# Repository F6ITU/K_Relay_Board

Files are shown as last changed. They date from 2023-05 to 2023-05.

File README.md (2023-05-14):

# K_Relay_Board
LA2NI's OpenHPSDR 4 ways HF relay board (Kicad Version)

OpenHPSDR P.A. Antenna switch board by LA2NI (Munin 400/Aries system)

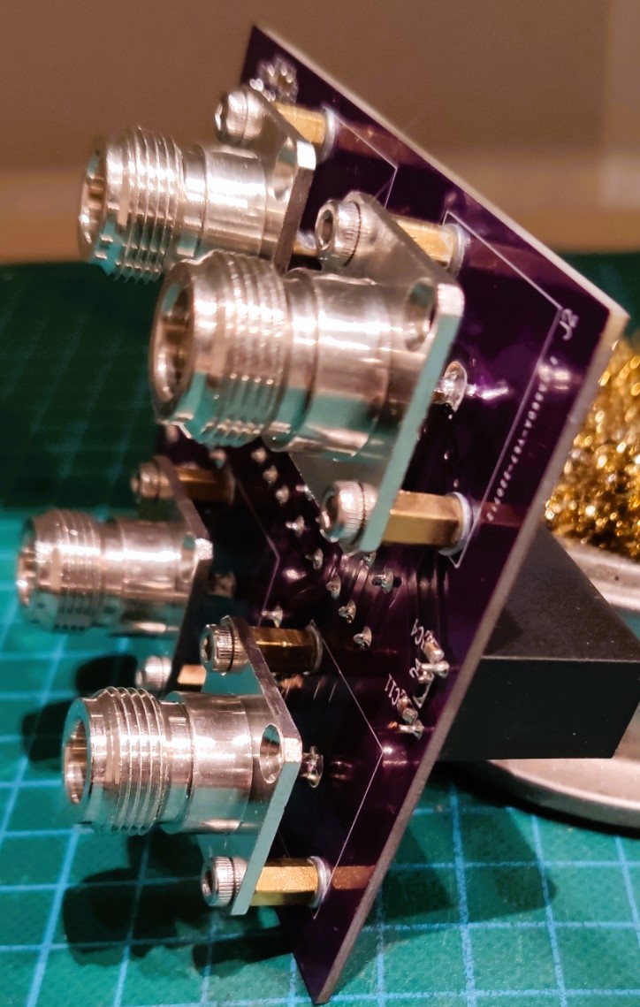
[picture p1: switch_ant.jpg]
La carte antenne


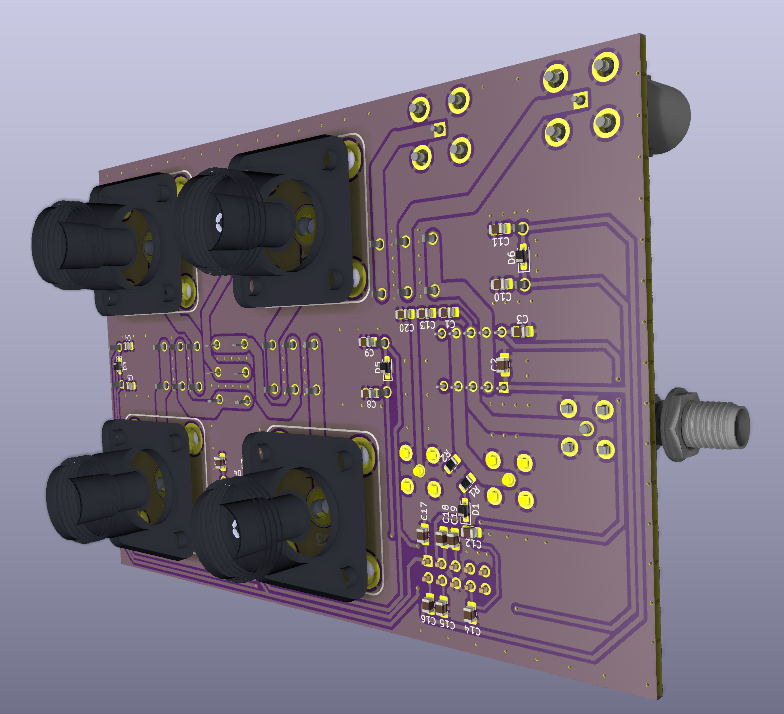
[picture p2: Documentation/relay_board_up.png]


This relay board is part of a set consisting of a 400 W LDMos based RF power amplifier (Munin 400), 
a medium power (600 or 1500 W) Zolotarev low pass filter, an Automatic Antenna Tuner (ATU) nickname « Aries » 
and a 4 port antenna switch (this project).

All these developments are the work and intellectual property of Kjell Karlsen LA2NI and Laurence Barker G8NJJ.

This original work can be downloaded from 

https://github.com/LA2NI/

https://github.com/laurencebarker

The Antenna switch board ensures the switching between 4 antennas under the control of the Aries ATU board. Each of the connected antennas
have a profile stored in the memory of the Aries MCU module. This way, switching from an antenna to the other don't need a new 
tuning solution if the couple "frequency/antenna" has already been defined. 

For more information, please refer to the Aries documentation (in the G8NJJ github repository)

This board was originally developed in September 2021 by Kjell LA2NI , with UltiBoard EDA. This repository is a « bug for bug » clone of the original Protection Board using the Opensource 
Kicad EDA. All these KiCad files are, consequently, the intellectual property of Kjell LA2NI.

This portage (convertion/translation) is placed under the CERN Open source/ Open hardware Licence.

Kicad is an Opensource EDA software maintained by the European Reseach Center CERN (Conseil européen pour la recherche nucléaire)

The original work is protected by the TAPR Open Hardware licence

# Work is RTM
Design is considered as finished, no prototype have been assembled so far. This project is RTM without waranty 

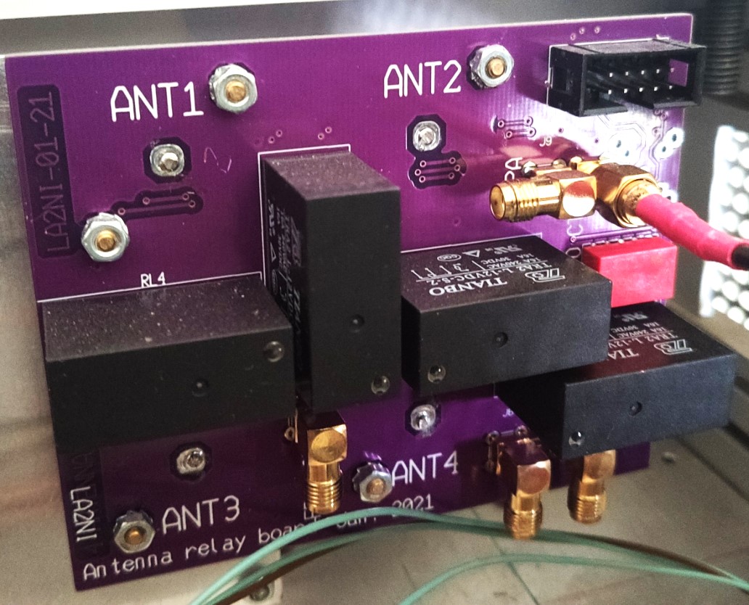
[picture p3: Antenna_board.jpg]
La carte antenne, verso

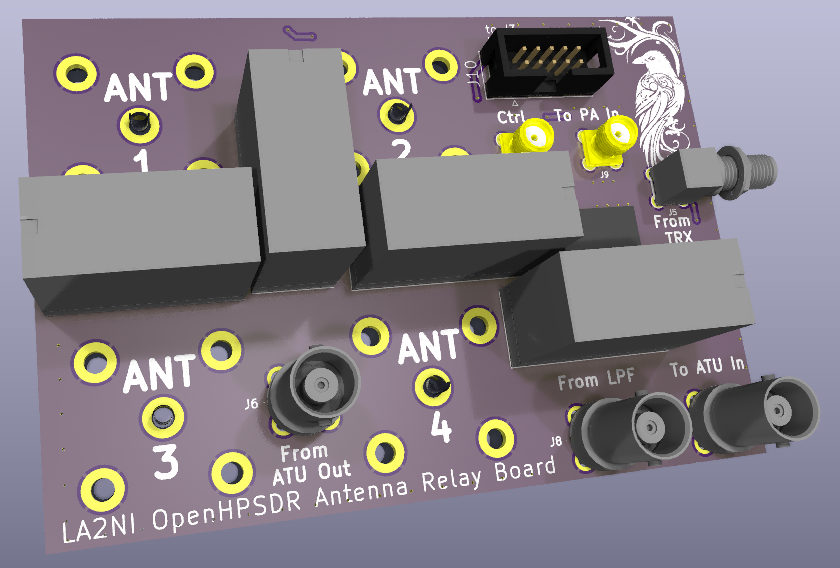
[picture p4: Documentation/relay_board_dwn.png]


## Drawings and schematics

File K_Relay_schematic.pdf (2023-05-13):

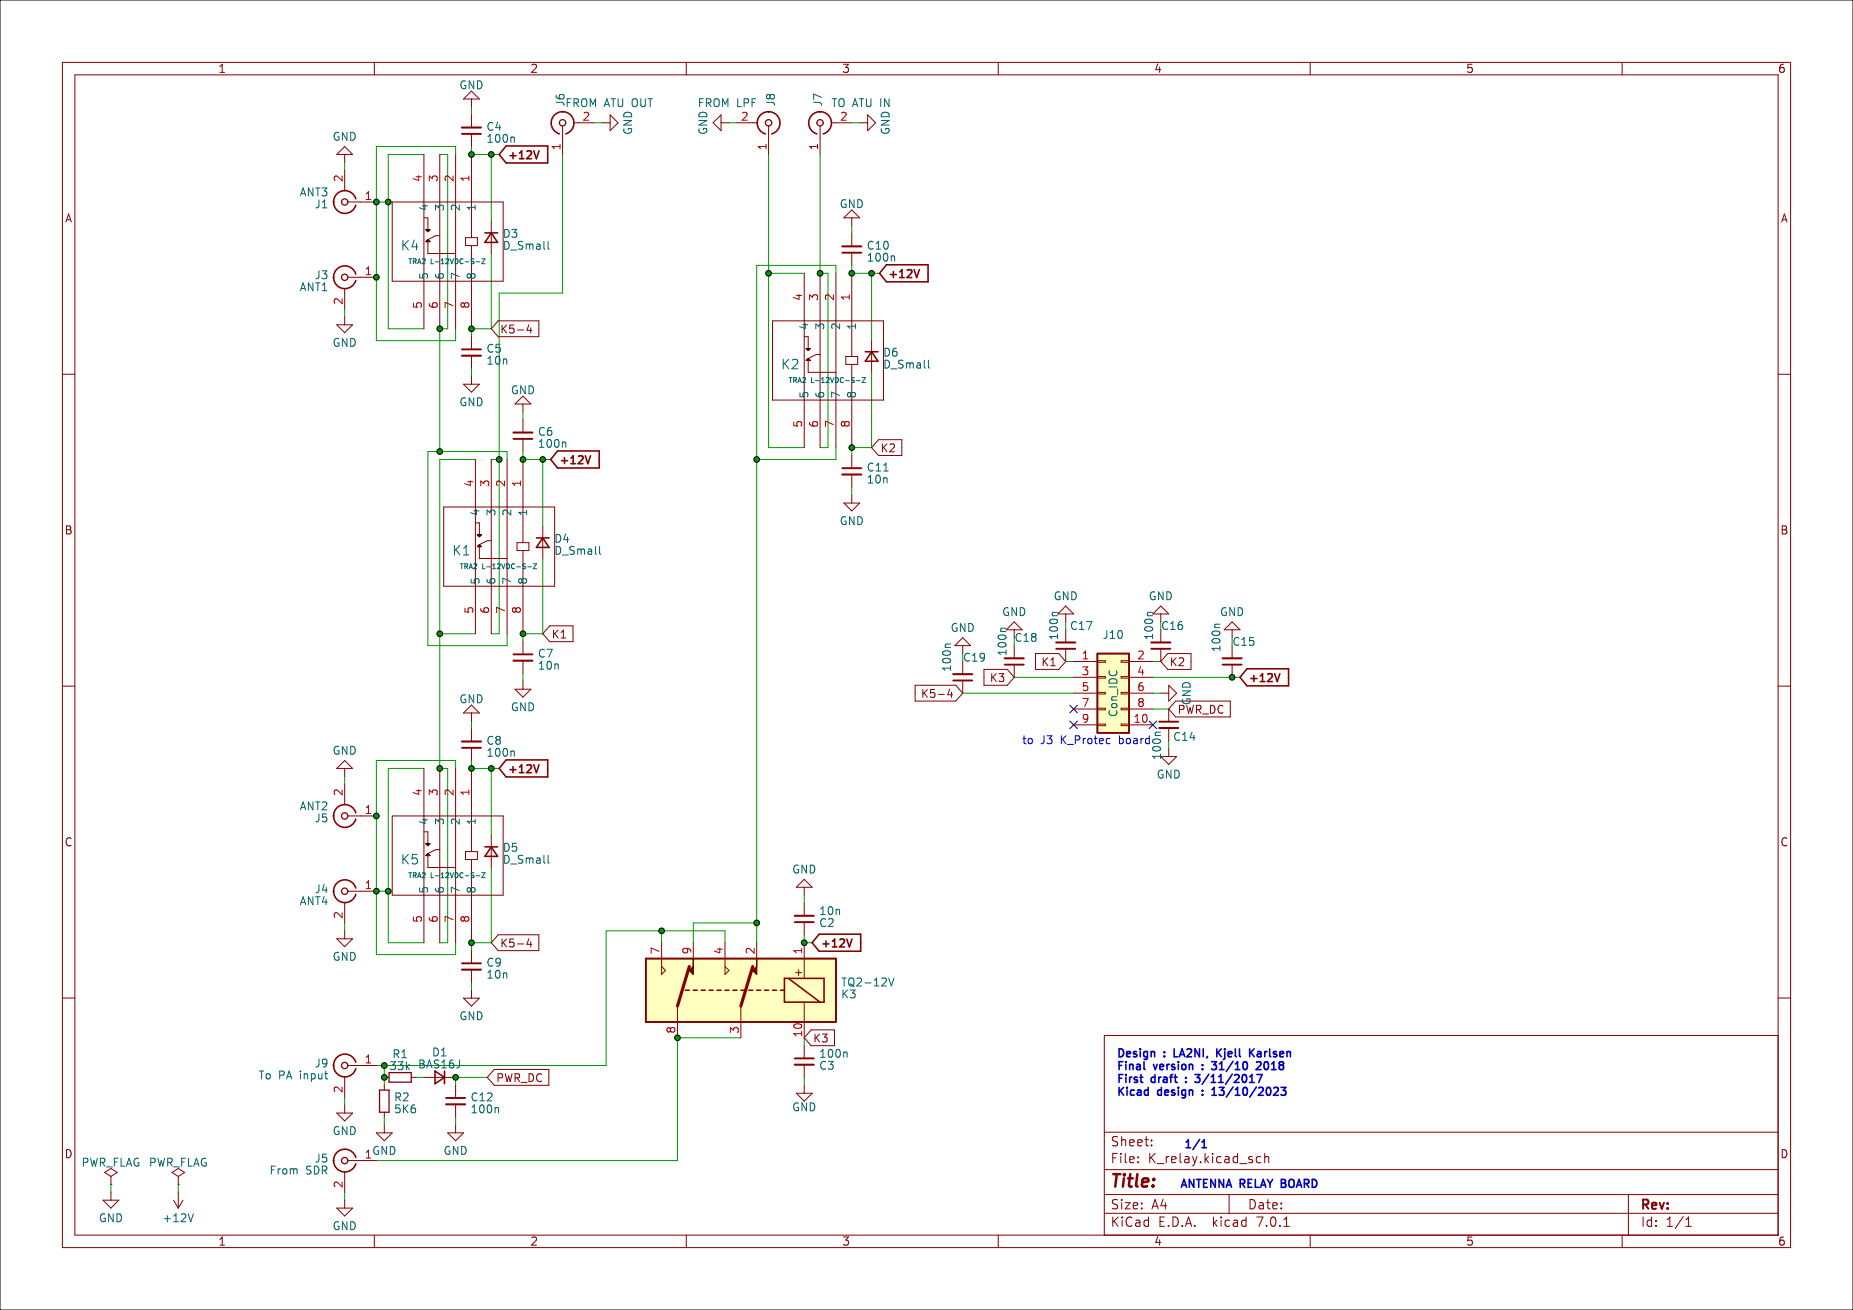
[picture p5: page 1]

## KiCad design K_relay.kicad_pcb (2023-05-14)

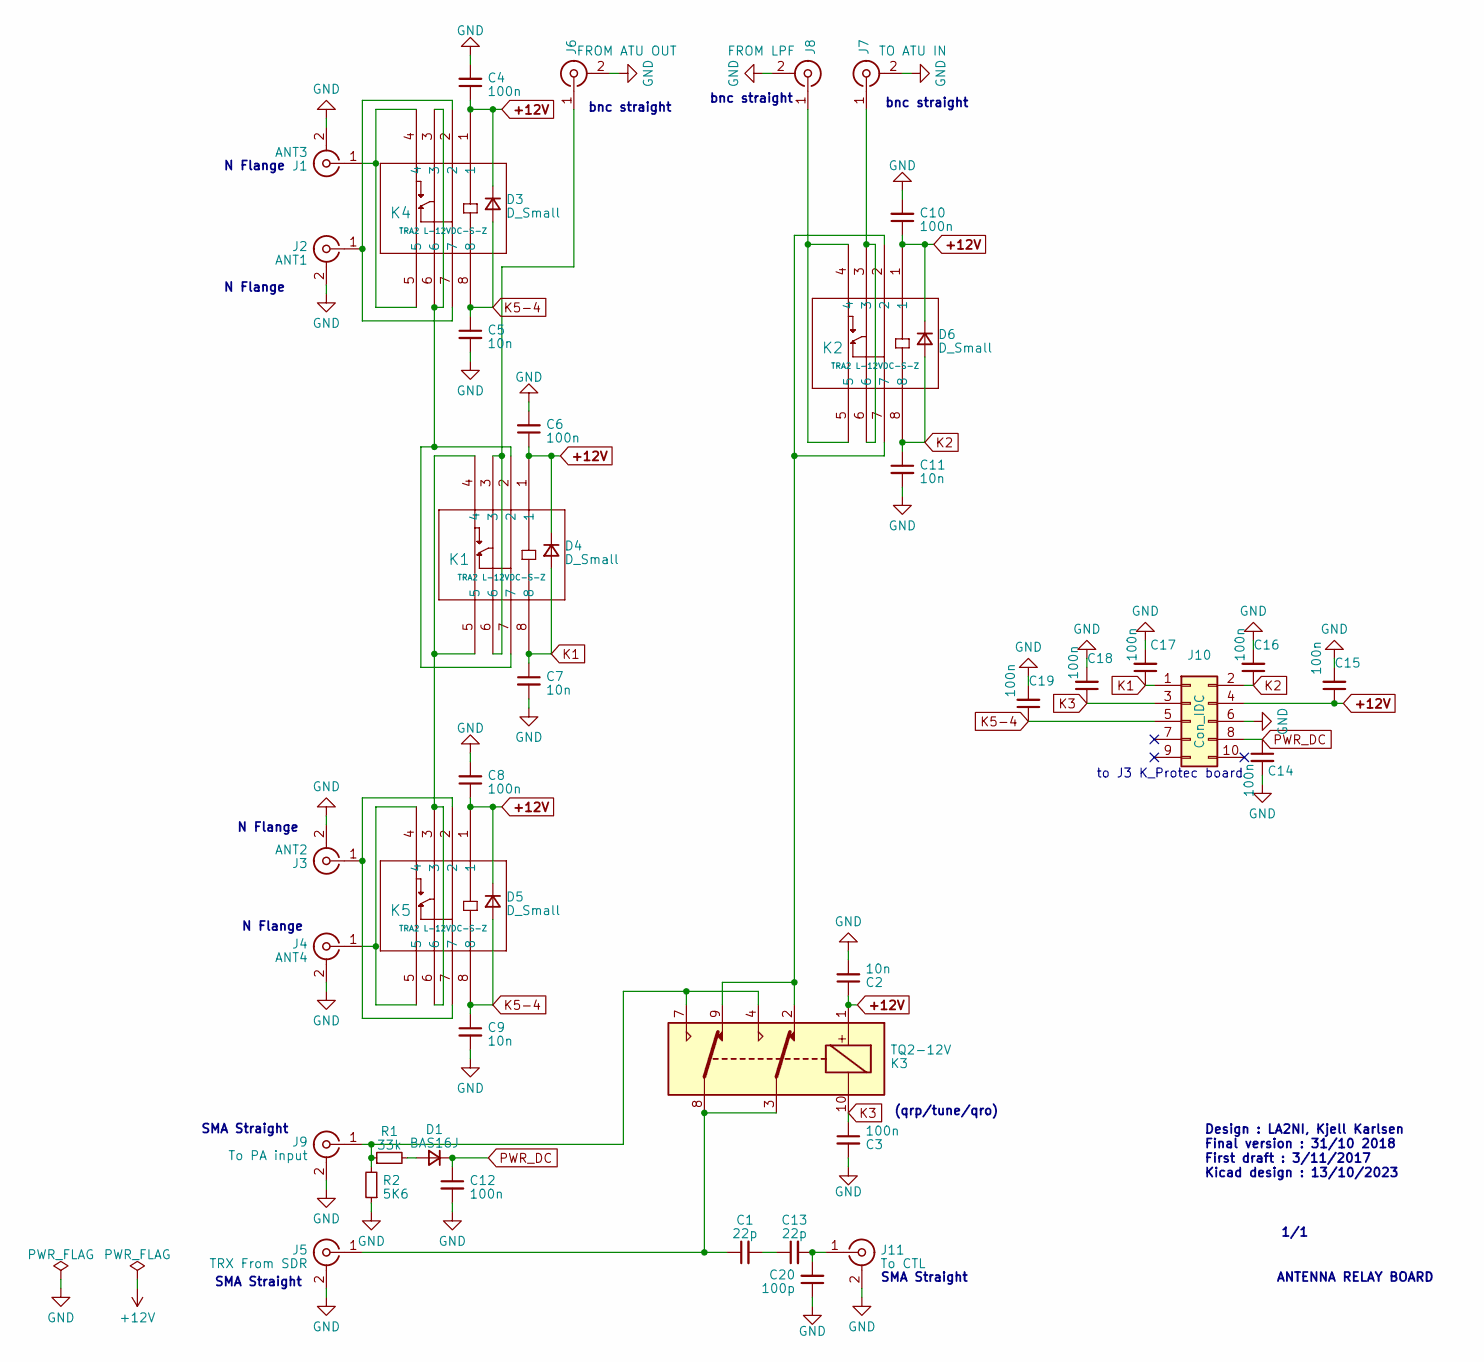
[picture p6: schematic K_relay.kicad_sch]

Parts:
C1, C13: 22p; C_0805_2012Metric_Pad1.18x1.45mm_HandSolder
C2, C5, C7, C9, C11: 10n; C_0805_2012Metric_Pad1.18x1.45mm_HandSolder
C3, C4, C6, C8, C10, C12, C14, C15, C16, C17, C18, C19: 100n; C_0805_2012Metric_Pad1.18x1.45mm_HandSolder
C20: 100p; C_0805_2012Metric_Pad1.18x1.45mm_HandSolder
D1: BAS16J; D_SOD-323_HandSoldering
D3, D4, D5, D6: D_Small; D_SOD-323_HandSoldering
J1: ANT3; Coaxial_N_Flange
J2: ANT1; Coaxial_N_Flange
J3: ANT2; Coaxial_N_Flange
J4: ANT4; Coaxial_N_Flange
J5: TRX From SDR; SMA_PINS
J6: FROM ATU OUT; BNC_Amphenol_031532951RFX
J7: TO ATU IN; BNC_Amphenol_031532951RFX
J8: FROM LPF; BNC_Amphenol_031532951RFX
J9: To PA input; SMA_PINS
J10: Con_IDC; IDC-Header_2x05_P2.54mm_Vertical
J11: To CTL; SMA_PINS
K1, K2, K4, K5: TRA2 L-12VDC-S-Z; RELAY_G2R-1-E AC12
K3: TQ2-12V; DIPS762W80P254L1400H530Q10N
R1: 33k; R_0805_2012Metric_Pad1.20x1.40mm_HandSolder
R2: 5K6; R_0805_2012Metric_Pad1.20x1.40mm_HandSolder

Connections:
+12V: C2.1, C4.1, C6.1, C8.1, C10.1, C15.1, D3.1 (K), D4.1 (K), D5.1 (K), D6.1 (K), J10.4, K1.1, K2.1, K3.1, K4.1, K5.1
GND: C2.2, C3.2, C4.2, C5.2, C6.2, C7.2, C8.2, C9.2, C10.2, C11.2, C12.2, C14.2, C15.2, C16.2, C17.2, C18.2, C19.2, C20.1, J1.2 (Ext), J2.2 (Ext), J3.2 (Ext), J4.2 (Ext), J5.2 (Ext), J6.2 (Ext), J7.2 (Ext), J8.2 (Ext), J9.2 (Ext), J10.6, J11.2 (Ext), R2.1
K1: C7.1, C17.1, D4.2 (A), J10.1, K1.8
K2: C11.1, C16.1, D6.2 (A), J10.2, K2.8
K3: C3.1, C18.1, J10.3, K3.10
K5-4: C5.1, C9.1, C19.1, D3.2 (A), D5.2 (A), J10.5, K4.8, K5.8
unnamed: C1.2, C13.1
unnamed: D1.2 (A), R1.2
unnamed: J1.1 (In), K4.4, K4.5
unnamed: J2.1 (In), K4.2, K4.7
unnamed: J3.1 (In), K5.2, K5.7
unnamed: J4.1 (In), K5.4, K5.5
unnamed: C1.1, J5.1 (In), K3.3, K3.8
unnamed: J6.1 (In), K1.3, K1.6
unnamed: J7.1 (In), K2.3, K2.6
unnamed: J8.1 (In), K2.4, K2.5
unnamed: J9.1 (In), K3.4, K3.7, R1.1, R2.2
unnamed: C13.2, C20.2, J11.1 (In)
unnamed: K1.2, K1.7, K4.3, K4.6
unnamed: K1.4, K1.5, K5.3, K5.6
unnamed: K2.2, K2.7, K3.2, K3.9
PWR_DC: C12.1, C14.1, D1.1 (K), J10.8

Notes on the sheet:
to J3 K_Protec board
N Flange
bnc straight
SMA Straight
1/1
Design : LA2NI, Kjell Karlsen Final version : 31/10 2018 First draft : 3/11/2017 Kicad design : 13/10/2023
(qrp/tune/qro)
ANTENNA RELAY BOARD

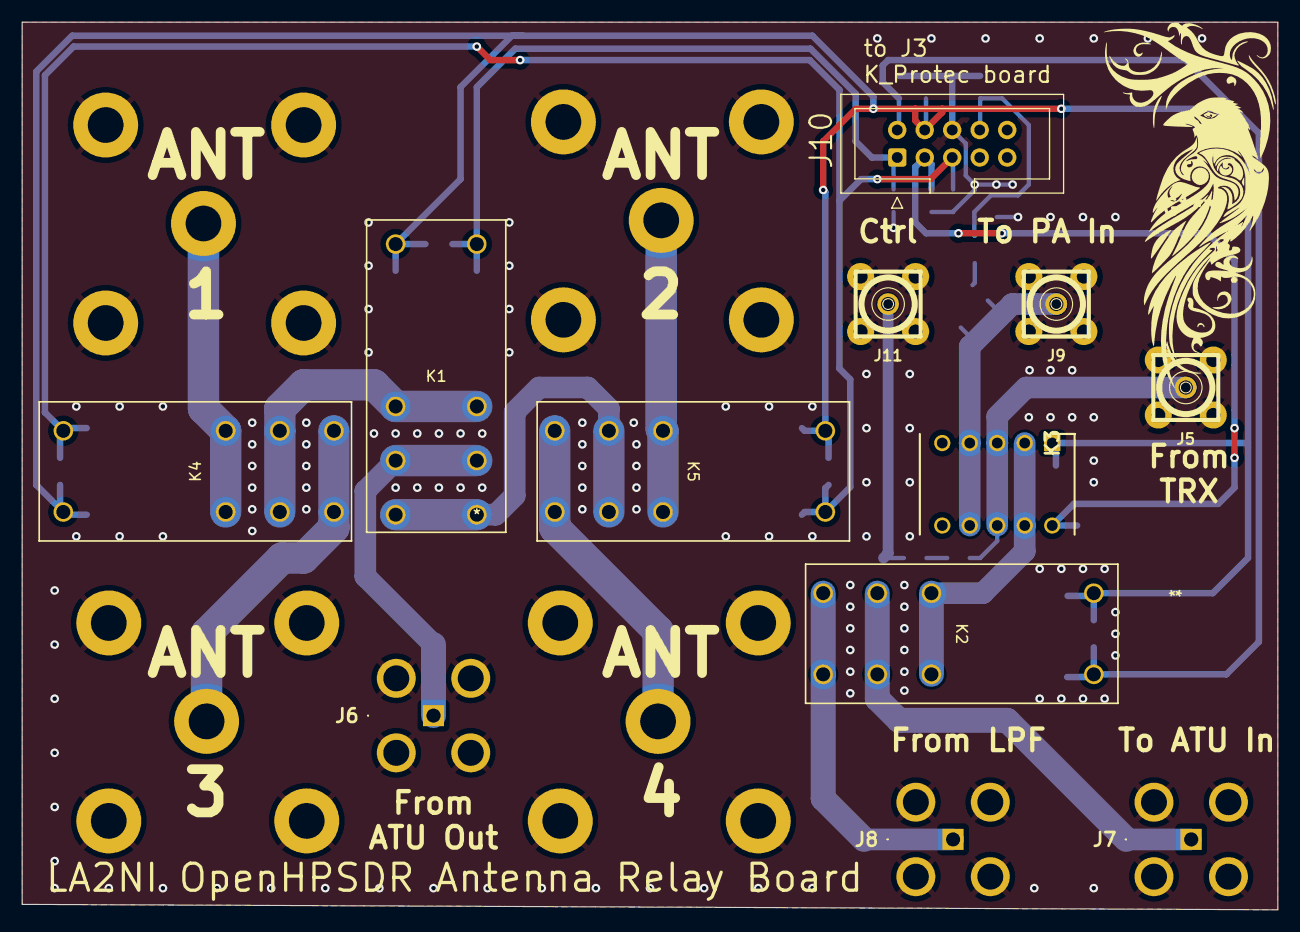
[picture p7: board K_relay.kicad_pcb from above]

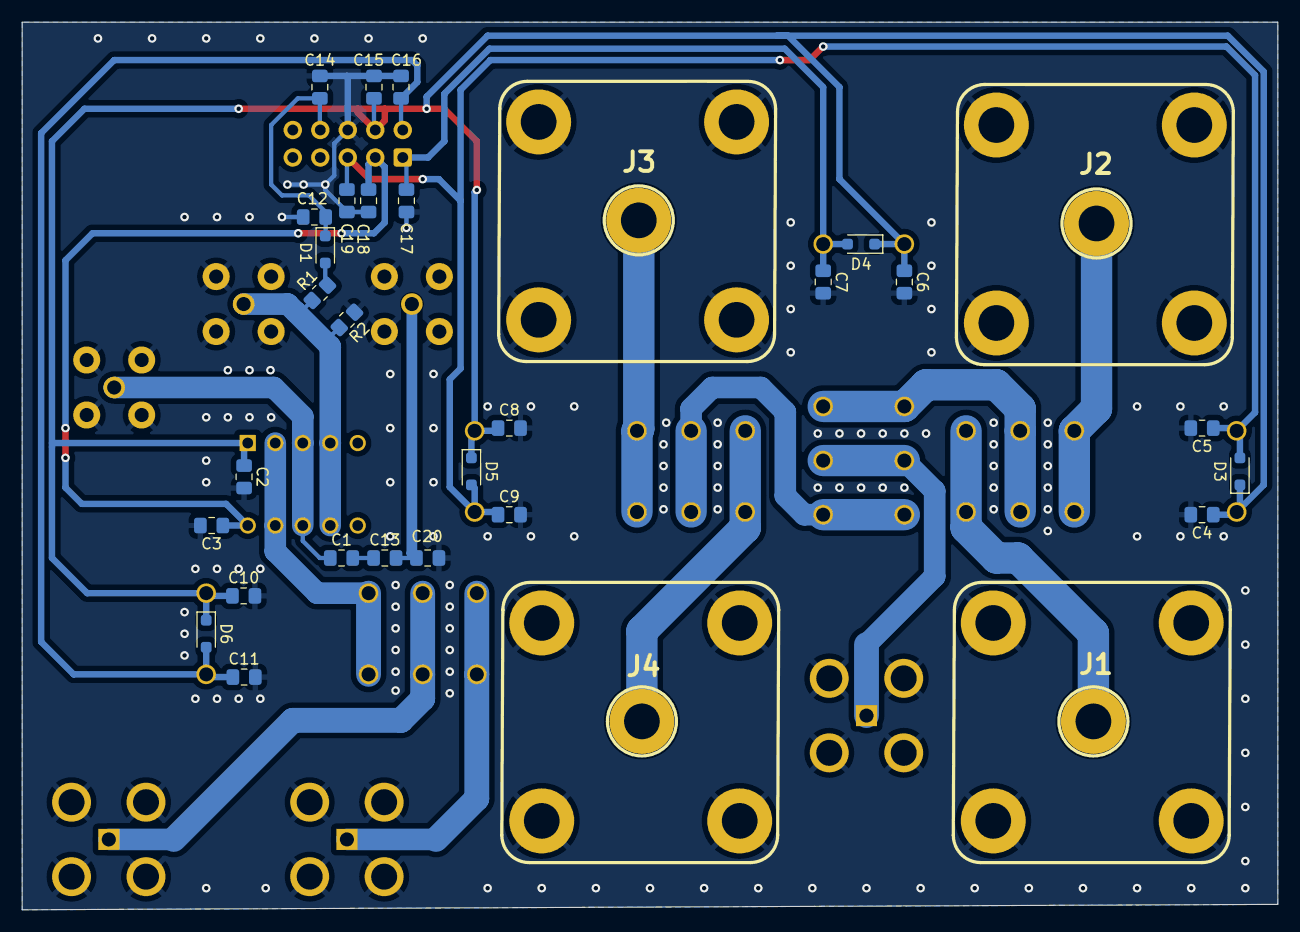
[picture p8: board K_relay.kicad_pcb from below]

Board: 2 copper layers, 116.0 x 82.0 mm, 43 parts (31 on the bottom side), 22 nets.

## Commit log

2023-05-13 schematic partialy done
    [K_relay.kicad_pcb, K_relay.kicad_sch]
2023-05-13 schematic completed
    [K_relay.kicad_sch]
2023-05-14 schematic completed, footprint & 3D shapes ok
    [K_relay.kicad_pcb, K_relay.kicad_sch]
2023-05-14 traces completed, silk need some cleaning
    [K_relay.kicad_pcb, K_relay.kicad_sch, b-cu.kicad_pcb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]
2023-05-14 minor mods in routing, silk cleaned, ibom and gerber ok
    [K_relay-B_Cu.gbl, K_relay-B_Mask.gbs, K_relay-B_Paste.gbp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]
